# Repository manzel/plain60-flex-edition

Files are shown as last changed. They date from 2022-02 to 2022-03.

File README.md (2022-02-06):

# Plain60 MKD Edition
This 60% PCB is a modified version of [Plain60 Flex Edition](https://github.com/evyd13/plain60-flex-edition) rev2.2 by [evyd13](https://github.com/evyd13).

In the German keyboard community (MKD), we were looking for a universal (in the sense of board compatibility, not layout support) flexible PCB supporting all of our 60% boards. As this was not available, we used a Plain60 Flex Edition as basis, removed some holes (layout options, that is) we deemed unnecessary, and added some in other places (cutouts). The result of this is the Plain60 MKD Edition available here.

We went for even less layout support, making a tsangan (7u) bottom row the only choice. Additionally, support for ANSI and ISO is not included in a single PCB, but two variants. A third (HHKB) variant was specifically created to fit the Kara, which does not exhibit any layout options except for normal or stepped Caps Lock.

Other changes include the relocation of the microcontroller to below the spacebar, avoiding a stiffer spot on the left of the alpha cluster. The JST connector was moved as close to the position found on the Bakeneko PCB as possible, without changing the flex cut. For cases using a daughterboard, the PCB can be assembled without the USB connector. On the other hand, one can also omit the JST connector and use the USB-C one instead. Of course, assembling both is also possible, if your board has space for that.

This PCB is intended to be produced in 1.2 mm thickness and was only tested in this configuration. Depending on your choice of stabilizers, you may need shims (3D printed or FR4) for a *stable* fit. However, even though untested, 1.6 mm should work as well.

The files were created in KiCad 5.99 Nightly and later re-saved in 6 Stable, they will not open in KiCad 5.

## Features
 - USB-C and/or JST connector (for unified daughterboard)
 - ESD protection and fuse
 - Atmega32U4-AU
 - ISP header
 - AST1109MLTRQ speaker

## ANSI Version
In its ANSI version, the PCB supports only full left Shift and ANSI Enter. There are options for stepped or normal Caps Lock, full or split right Shift, and full or split Backspace.
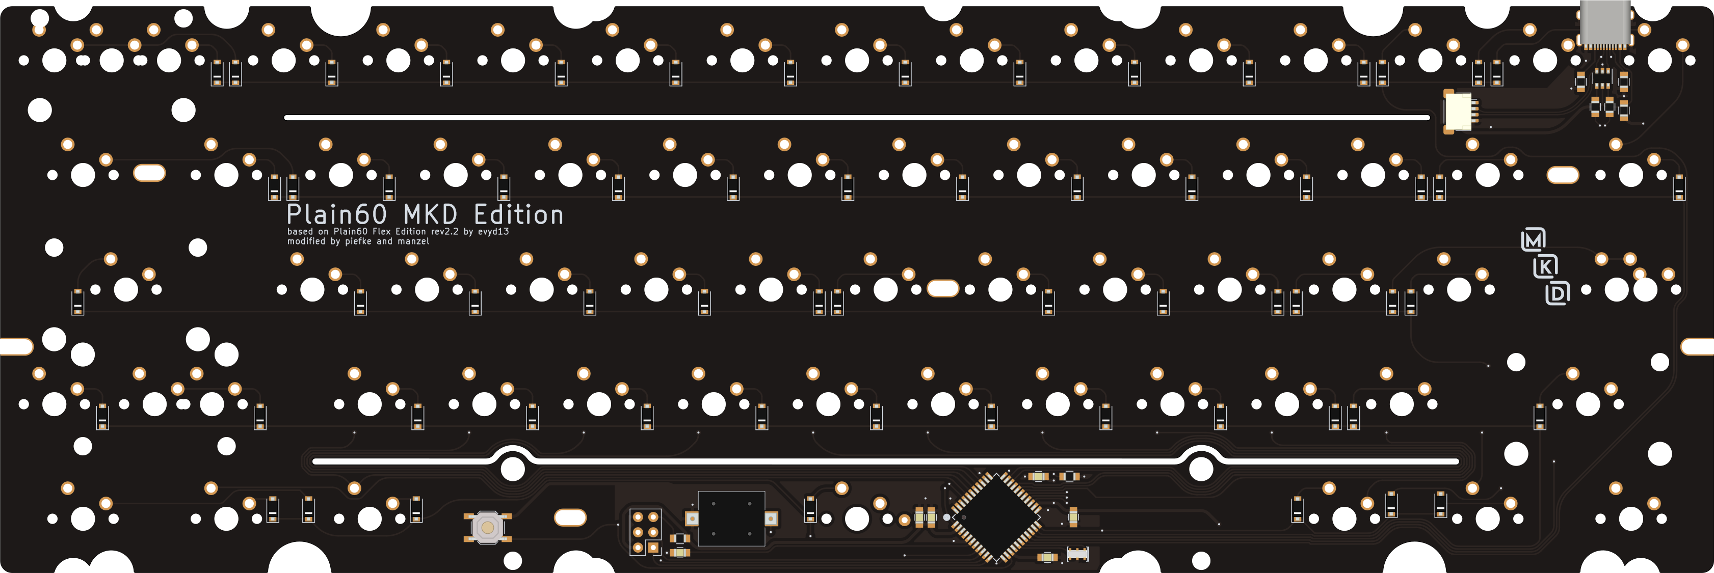
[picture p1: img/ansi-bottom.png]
ansi_bottom

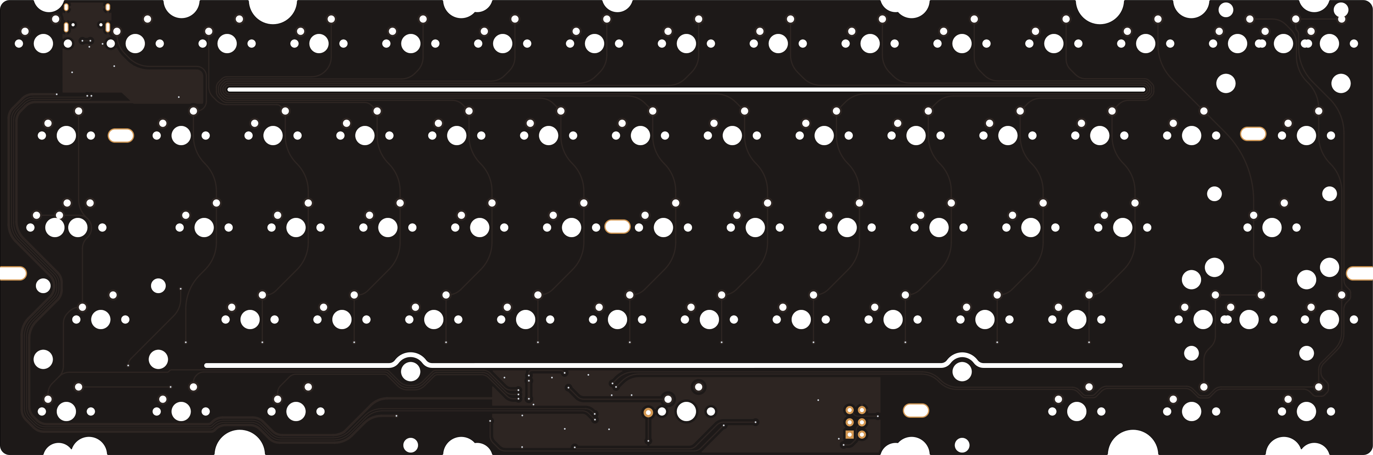
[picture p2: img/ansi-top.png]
ansi_top

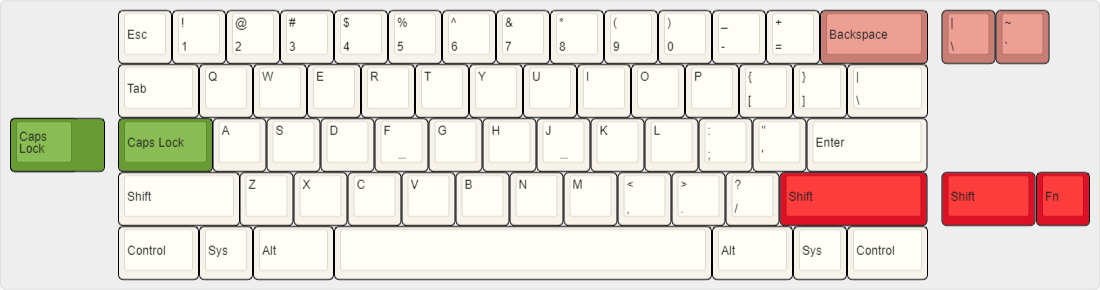
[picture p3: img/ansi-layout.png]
ansi_layout


## ISO Version
The ISO variant only supports split left Shift and ISO Enter. You can build with either stepped or normal Caps Lock, full or split right Shift, and full or split Backspace.
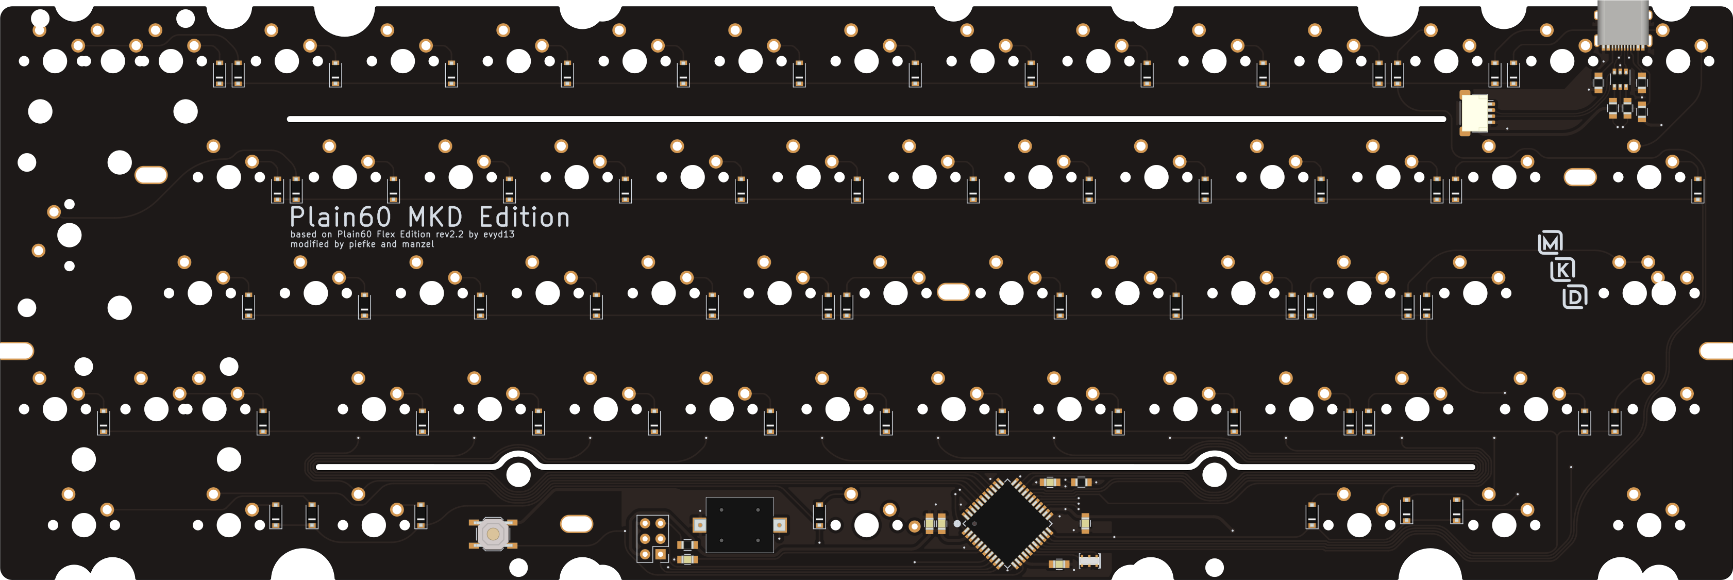
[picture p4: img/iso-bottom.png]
iso_bottom

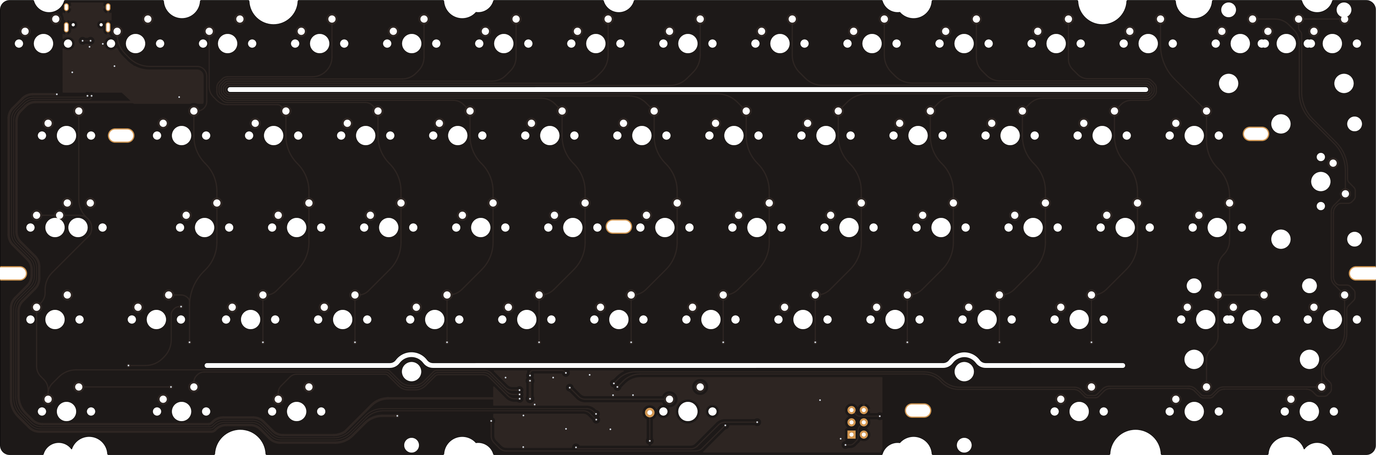
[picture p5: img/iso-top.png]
iso_top

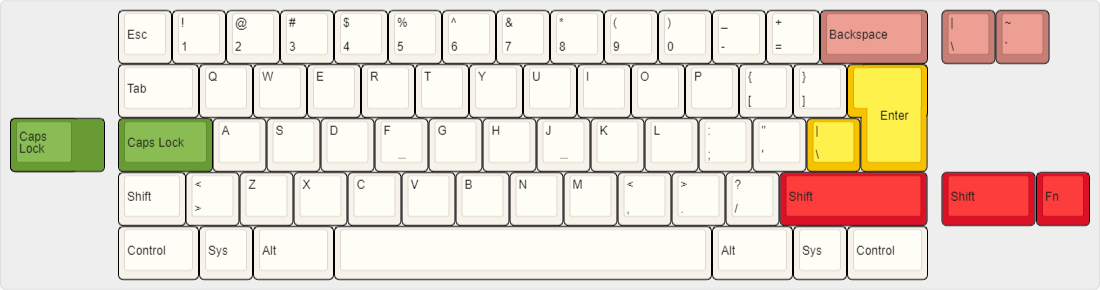
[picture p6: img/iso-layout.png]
iso_layout


## HHKB Version
The HHKB version was made specifically for the Kara, but can of course be used in other HHKB-style compatible boards. It retains stepped or normal Caps Lock as the only layout option, while being fixed to HHKB layout otherwise.
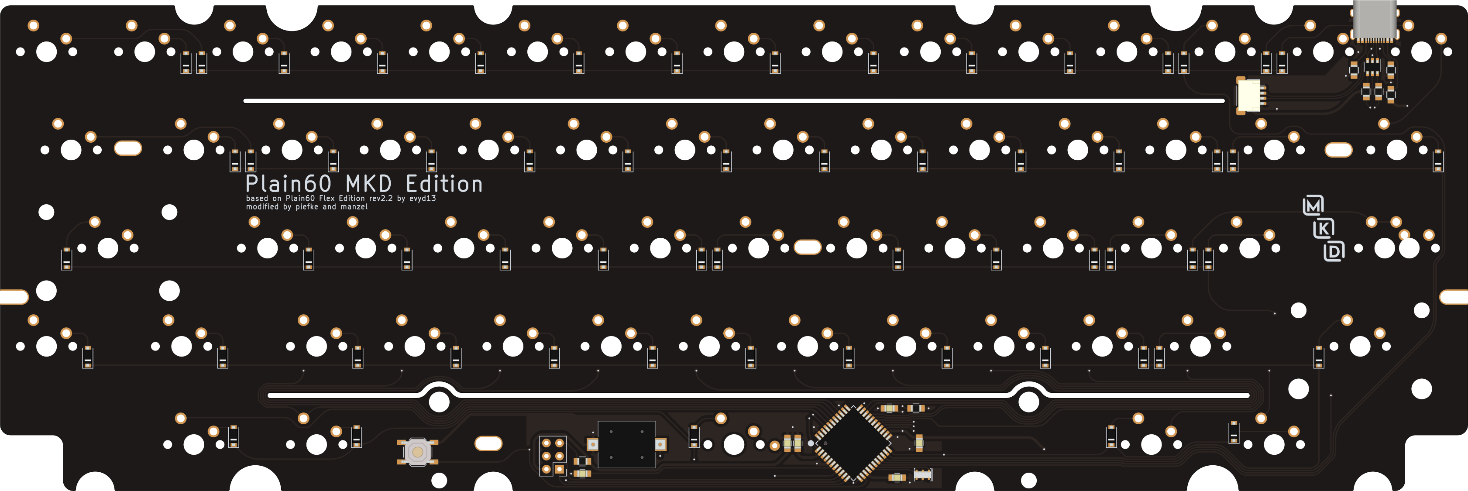
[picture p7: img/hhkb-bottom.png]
hhkb_bottom

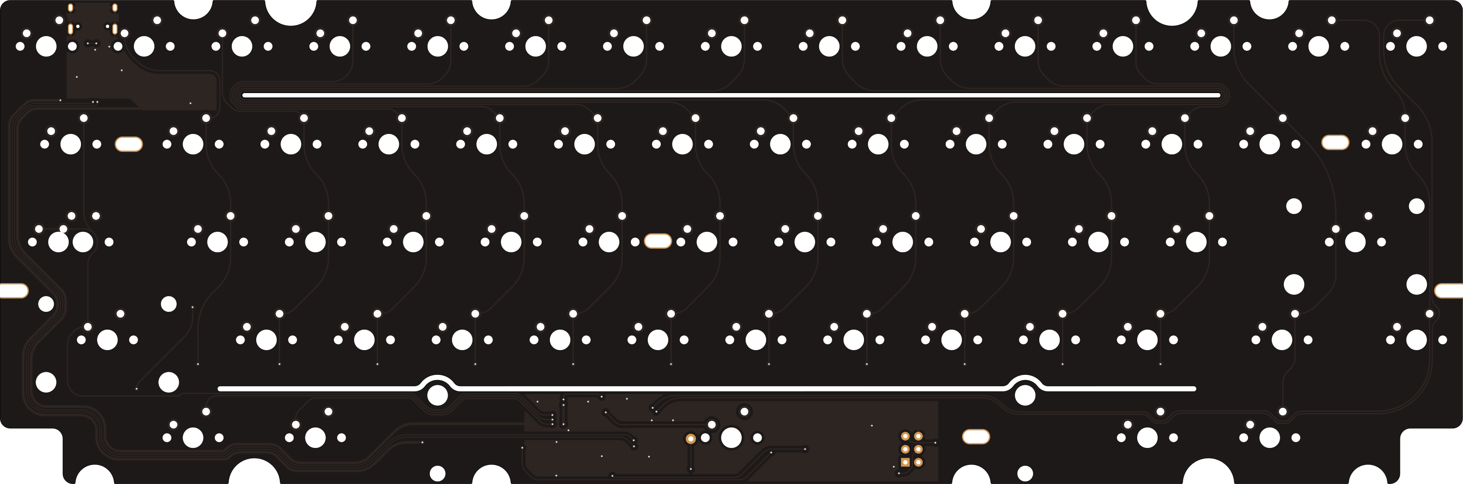
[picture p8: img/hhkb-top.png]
hhkb_top

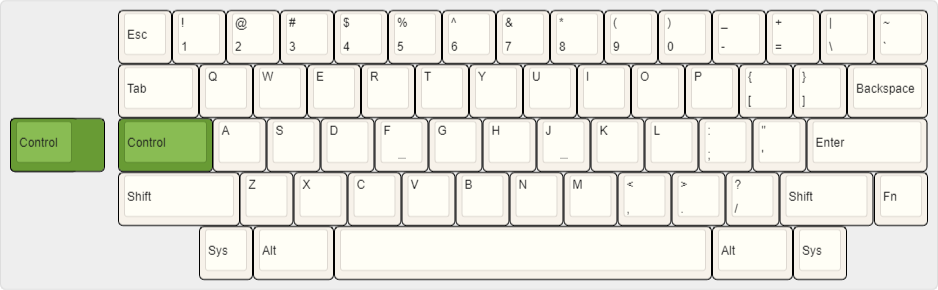
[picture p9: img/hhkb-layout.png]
hhkb_layout


## Production
Production files for JLCPCB (generated using the excellent [JLCKicadTools](https://github.com/matthewlai/JLCKicadTools)) are included. Part orientation in the CPL file was not checked as this seems to be automatically corrected by JLCPCB lately.

## Firmware
The needed QMK Firmware as well as VIA and Vial .hex and .json files are included in [firmware](./firmware/).

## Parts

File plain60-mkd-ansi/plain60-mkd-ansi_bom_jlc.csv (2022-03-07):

Comment | Designator | Footprint | LCSC Part #
1u | C1 | C_0805 | C28323
0.1u | C2,C3,C4,C5 | C_0805 | C49678
4.7u | C6 | C_0805 | C1779
D | D1,D2,D3,D4,D5,D6,D7,D8,D9,D10,D11,D12,D13,D14,D15,D16,D17,D18,D19,D20,D21,D22,D23,D24,D25,D26,D27,D28,D29,D31,D32,D33,D34,D35,D36,D37,D38,D39,D40,D41,D42,D44,D46,D48,D49,D50,D51,D52,D53,D54,D55,D56,D57,D58,D59,D61,D62,D63,D67,D72,D73,D74 | D_SOD-123 | C2099
Polyfuse | F1 | R_0805 | C261942
HRO-TYPE-C-31-M-12 | J1 | HRO-TYPE-C-31-M-12 | C165948
ai03_ud | J3 | JST_SH_SM04B-SRSS-TB_1x04-1MP_P1.00mm_Horizontal | C160404
Speaker | LS1 | speaker_AST1109MLTRQ | C391036
22 | R1,R2 | R_0805 | C17561
5.1k | R3,R4 | R_0805 | C27834
10k | R5,R6 | R_0805 | C17414
SW_PUSH | SW1 | SW_SPST_TL3342 | C92584
ATmega32U4 | U1 | ATMEGA32U4 | C44854
USBLC6-2SC6 | U2 | USBLC6-2SC6 | C7519
XTAL_GND | X1 | Resonator_SMD_muRata_CSTNExxV-3Pin-p1.2 | C783275

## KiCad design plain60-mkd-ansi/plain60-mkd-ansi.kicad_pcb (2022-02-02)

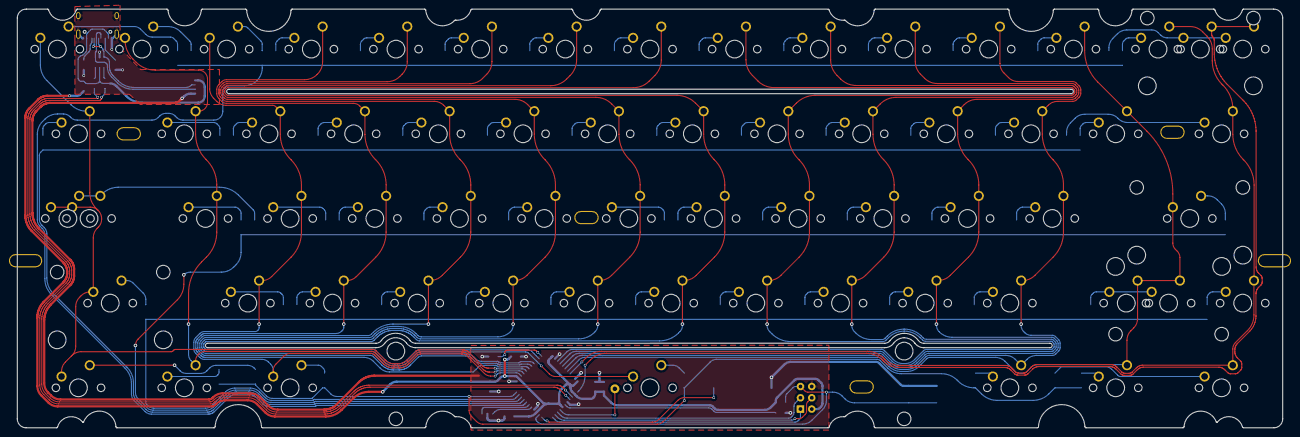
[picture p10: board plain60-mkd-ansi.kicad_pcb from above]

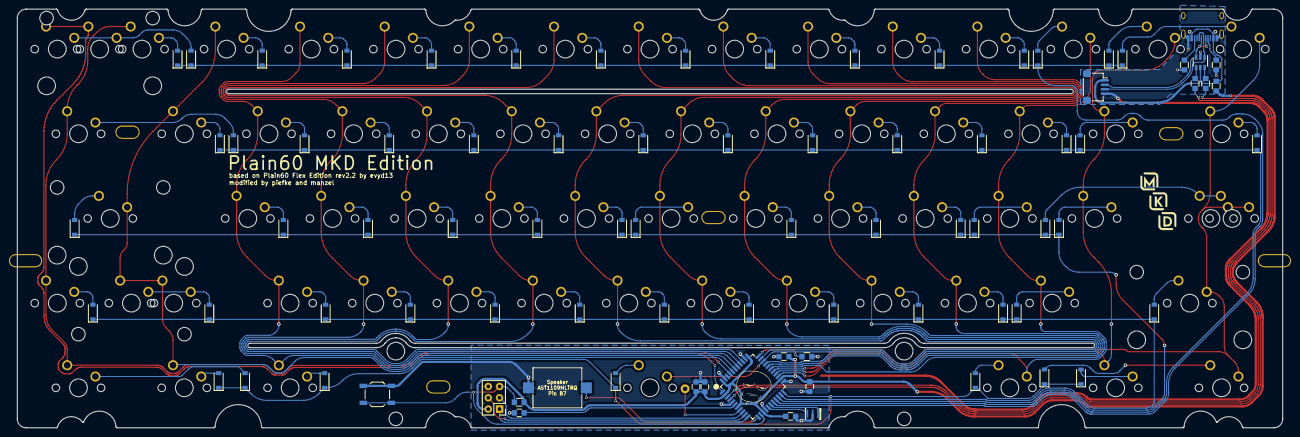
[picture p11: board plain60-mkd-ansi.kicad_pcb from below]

Board: 2 copper layers, 284.7 x 94.2 mm, 156 parts (85 on the bottom side), 103 nets.

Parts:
C1: 1u; C_0805
C2, C3, C4, C5: 0.1u; C_0805
C6: 4.7u; C_0805
D1, D2, D3, D4, D5, D6, D7, D8, D9, D10, D11, D12, D13, D14, D15, D16, D17, D18, D19, D20, D21, D22, D23, D24, D25, D26, D27, D28, D29, D31, D32, D33, D34, D35, D36, D37, D38, D39, D40, D41, D42, D44, D46, D48, D49, D50, D51, D52, D53, D54, D55, D56, D57, D58, D59, D61, D62, D63, D67, D72, D73, D74: D; D_SOD-123
F1: Polyfuse; R_0805
G2: LOGO; mkd-1u
H1: B0; free_pin
J1: HRO-TYPE-C-31-M-12
J2: ISP; isp_standard
J3: ai03_ud; JST_SH_SM04B-SRSS-TB_1x04-1MP_P1.00mm_Horizontal
K1, K2, K3, K4, K5, K6, K7, K8, K9, K10, K11, K12, K13, K14, K15-1, K17, K18, K19, K20, K21, K22, K23, K24, K25, K26, K27, K28, K32, K33, K34, K35, K36, K37, K38, K39, K40, K41, K42, K48, K49, K50, K51, K52, K53, K54, K55, K56, K57, K59, K62-1, K73-1: KEYSW; CHERRY_PLATE_100H
K15: KEYSW; CHERRY_PCB_200H
K16, K29, K61-1, K63-1, K72-1, K74-1: KEYSW; CHERRY_PLATE_150H
K31, K58-1: KEYSW; CHERRY_PLATE_175H
K31-1: KEYSW; CHERRY_PLATE_125H
K44, K46: KEYSW; CHERRY_PCB_225H
K58: KEYSW; CHERRY_PCB_275H
K67-1: KEYSW; CHERRY_PCB_700H_F
LS1: Speaker; speaker_AST1109MLTRQ
R1, R2: 22; R_0805
R3, R4: 5.1k; R_0805
R5, R6: 10k; R_0805
S1, S2, S3, S6: Screw; 5.5_5x2.5mm
S4, S5: Screw; 10x5_7x2.5mm
SW1: SW_PUSH; SW_SPST_TL3342
U1: ATmega32U4; ATMEGA32U4
U2: USBLC6-2SC6
X1: XTAL_GND; Resonator_SMD_muRata_CSTNExxV-3Pin-p1.2

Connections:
D+: J1.6 (DP1), J1.8 (DP2), J3.3, U2.1 (I/O1)
D-: J1.5 (DN2), J1.7 (DN1), J3.2, U2.3 (I/O2)
Da+: R1.1, U1.4 (D+)
Da-: R2.2, U1.3 (D-)
GND: C1.2, C2.1, C3.1, C4.1, C5.1, C6.1, J1.1 (GND), J1.12 (GND), J1.13 (SHIELD), J2.6, J3.4, LS1.2, R3.1, R4.2, R6.1, SW1.1, U1.5 (UGND), U1.15 (GND), U1.23 (GND), U1.35 (GND), U1.43 (GND), U2.2 (GND), X1.3
MISO: J2.1, U1.11 ((PDO/MISO/PCINT3)PB3)
MOSI: J2.4, U1.10 ((PDI/MOSI/PCINT2)PB2)
unnamed: C1.1, U1.6 (UCAP)
unnamed: D1.2 (A), K1.1
unnamed: D2.2 (A), K2.1
unnamed: D3.2 (A), K3.1
unnamed: D4.2 (A), K4.2
unnamed: D5.2 (A), K5.2
unnamed: D6.2 (A), K6.2
unnamed: D7.2 (A), K7.2
unnamed: D8.2 (A), K8.2
unnamed: D9.2 (A), K9.2
unnamed: D10.2 (A), K10.2
unnamed: D11.2 (A), K11.2
unnamed: D12.2 (A), K12.2
unnamed: D13.2 (A), K13.2
unnamed: D14.2 (A), K14.2
unnamed: D15.2 (A), K15.2, K15-1.2
unnamed: D16.2 (A), K16.2
unnamed: D17.2 (A), K17.2
unnamed: D18.2 (A), K18.2
unnamed: D19.2 (A), K19.2
unnamed: D20.2 (A), K20.2
unnamed: D21.2 (A), K21.2
unnamed: D22.2 (A), K22.2
unnamed: D23.2 (A), K23.2
unnamed: D24.2 (A), K24.2
unnamed: D25.2 (A), K25.2
unnamed: D26.2 (A), K26.2
unnamed: D27.2 (A), K27.2
unnamed: D28.2 (A), K28.2
unnamed: D29.2 (A), K29.2
unnamed: D31.2 (A), K31.1, K31-1.1
unnamed: D32.2 (A), K32.2
unnamed: D33.2 (A), K33.2
unnamed: D34.2 (A), K34.2
unnamed: D35.2 (A), K35.2
unnamed: D36.2 (A), K36.2
unnamed: D37.2 (A), K37.2
unnamed: D38.2 (A), K38.2
unnamed: D39.2 (A), K39.2
unnamed: D40.2 (A), K40.2
unnamed: D41.2 (A), K41.2
unnamed: D42.2 (A), K42.2
unnamed: D44.2 (A), K44.1
unnamed: D46.2 (A), K46.1
unnamed: D48.2 (A), K48.2
unnamed: D49.2 (A), K49.2
unnamed: D50.2 (A), K50.2
unnamed: D51.2 (A), K51.2
unnamed: D52.2 (A), K52.2
unnamed: D53.2 (A), K53.2
unnamed: D54.2 (A), K54.2
unnamed: D55.2 (A), K55.2
unnamed: D56.2 (A), K56.2
unnamed: D57.2 (A), K57.2
unnamed: D58.2 (A), K58.2, K58-1.2
unnamed: D59.2 (A), K59.2
unnamed: D61.2 (A), K61-1.1
unnamed: D62.2 (A), K62-1.2
unnamed: D63.2 (A), K63-1.1
unnamed: D67.2 (A), K67-1.1
unnamed: D72.2 (A), K72-1.2
unnamed: D73.2 (A), K73-1.2
unnamed: D74.2 (A), K74-1.2
unnamed: H1.1, U1.8 ((SS/PCINT0)PB0)
unnamed: J1.4 (CC1), R3.2
unnamed: J1.10 (CC2), R4.1
unnamed: LS1.1, U1.12 ((OC0A/OC1C/~RTS~/PCINT7)PB7)
unnamed: R1.2, U2.6 (I/O1)
unnamed: R2.1, U2.4 (I/O2)
unnamed: R6.2, U1.33 ((~HWB~)PE2)
unnamed: U1.16 (XTAL2), X1.2
unnamed: U1.17 (XTAL1), X1.1
RST: J2.5, R5.1, SW1.2, U1.13 (RESET)
SCK: J2.3, U1.9 ((SCLK/PCINT1)PB1)
VBUS: F1.2, J1.2 (VBUS), J1.11 (VBUS), J3.1, U2.5 (VBUS)
VCC: C2.2, C3.2, C4.2, C5.2, C6.2, F1.1, J2.2, R5.2, U1.2 (UVCC), U1.7 (VBUS), U1.14 (VCC), U1.24 (AVCC), U1.34 (VCC), U1.44 (AVCC)
col0: K1.2, K16.1, K31.2, K31-1.2, K46.2, K61-1.2, U1.27 ((T0/OC4D/ADC10)PD7)
col1: K2.2, K17.1, K32.1, K62-1.1, U1.26 ((T1/~OC4D~/ADC9)PD6)
col2: K3.2, K18.1, K33.1, K48.1, K63-1.2, U1.25 ((ICP2/ADC8)PD4)
col3: K4.1, K19.1, K34.1, K49.1, U1.28 ((ADC11/PCINT4)PB4)
col4: K5.1, K20.1, K35.1, K50.1, U1.29 ((ADC12/OC1A/~OC4B~/PCINT12)PB5)
col5: K6.1, K21.1, K36.1, K51.1, U1.30 ((ADC13/OC1B/OC4B/PCINT13)PB6)
col6: K7.1, K22.1, K37.1, K52.1, K67-1.2, U1.31 ((OC3A/~OC4A~)PC6)
col7: K8.1, K23.1, K38.1, K53.1, U1.32 ((ICP3/CLK0/OC4A)PC7)
col8: K9.1, K24.1, K39.1, K54.1, U1.36 ((ADC7/TDI)PF7)
col9: K10.1, K25.1, K40.1, K55.1, U1.37 ((ADC6/TDO)PF6)
col10: K11.1, K26.1, K41.1, K56.1, U1.38 ((ADC5/TMS)PF5)
col11: K12.1, K27.1, K42.1, K57.1, K72-1.1, U1.39 ((ADC4/TCK)PF4)
col12: K13.1, K28.1, K44.2, K58.1, K58-1.1, K73-1.1, U1.40 ((ADC1)PF1)
col13: K14.1, K29.1, K59.1, K74-1.1, U1.41 ((ADC0)PF0)
col14: K15.1, K15-1.1, U1.1 ((INT6/AIN0)PE6)
row0: D1.1 (K), D2.1 (K), D3.1 (K), D4.1 (K), D5.1 (K), D6.1 (K), D7.1 (K), D8.1 (K), D9.1 (K), D10.1 (K), D11.1 (K), D12.1 (K), D13.1 (K), D14.1 (K), D15.1 (K), U1.18 ((OC0B/SCL/INT0)PD0)
row1: D16.1 (K), D17.1 (K), D18.1 (K), D19.1 (K), D20.1 (K), D21.1 (K), D22.1 (K), D23.1 (K), D24.1 (K), D25.1 (K), D26.1 (K), D27.1 (K), D28.1 (K), D29.1 (K), U1.19 ((SDA/INT1)PD1)
row2: D31.1 (K), D32.1 (K), D33.1 (K), D34.1 (K), D35.1 (K), D36.1 (K), D37.1 (K), D38.1 (K), D39.1 (K), D40.1 (K), D41.1 (K), D42.1 (K), D44.1 (K), U1.20 ((RXD/INT2)PD2)
row3: D46.1 (K), D48.1 (K), D49.1 (K), D50.1 (K), D51.1 (K), D52.1 (K), D53.1 (K), D54.1 (K), D55.1 (K), D56.1 (K), D57.1 (K), D58.1 (K), D59.1 (K), U1.21 ((TXD/INT3)PD3)
row4: D61.1 (K), D62.1 (K), D63.1 (K), D67.1 (K), D72.1 (K), D73.1 (K), D74.1 (K), U1.22 ((XCK1/~CTS~)PD5)

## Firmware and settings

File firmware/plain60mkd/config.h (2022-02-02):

/*
Copyright 2022 manzel

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
You should have received a copy of the GNU General Public License
along with this program.  If not, see <http://www.gnu.org/licenses/>.
*/

#pragma once

#include "config_common.h"

/* USB Device descriptor parameter */
#define VENDOR_ID       0x474C
#define PRODUCT_ID      0x5060
#define DEVICE_VER      0x0001
#define MANUFACTURER    MKD
#define PRODUCT         Plain60

/* key matrix size */
#define MATRIX_ROWS 5
#define MATRIX_COLS 15

// ROWS: Top to bottom, COLS: Left to right

#define MATRIX_ROW_PINS {D0,D1,D2,D3,D5}
#define MATRIX_COL_PINS {D7,D6,D4,B4,B5,B6,C6,C7,F7,F6,F5,F4,F1,F0,E6}

/* COL2ROW or ROW2COL */
#define DIODE_DIRECTION COL2ROW

/* define if matrix has ghost */
//#define MATRIX_HAS_GHOST

/* Set 0 if debouncing isn't needed */
#define DEBOUNCE 5

#define QMK_ESC_OUTPUT D7 // usually COL
#define QMK_ESC_INPUT D0 // usually ROW

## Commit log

2022-02-01 Initial commit of KiCad files for all three versions
    [plain60-flex-edition.kicad_pcb, plain60-flex-edition.kicad_sch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]
2022-02-01 Added PCB renders
2022-02-02 Cropped PCB renders
2022-02-02 Updated for KiCad 6
    [plain60-mkd-ansi.kicad_pcb, plain60-mkd-ansi.kicad_sch, plain60-mkd-hhkb.kicad_pcb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]
2022-03-07 Updated .gitignore and added SMT files
    [plain60-mkd-ansi_bom_jlc.csv, plain60-mkd-hhkb_bom_jlc.csv, plain60-mkd-iso_bom_jlc.csv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]

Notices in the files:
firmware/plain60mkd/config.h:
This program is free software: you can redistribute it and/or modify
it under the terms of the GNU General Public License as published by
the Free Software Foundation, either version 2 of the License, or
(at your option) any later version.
